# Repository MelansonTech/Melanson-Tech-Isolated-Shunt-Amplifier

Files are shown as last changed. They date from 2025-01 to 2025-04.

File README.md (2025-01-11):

Project Title: Isolated Shunt Amplifier
Overview:
Introducing the Isolated Shunt Amplifier, an open-source electronics project designed to provide precise and isolated measurements in high-voltage applications. This compact amplifier, based on the Si8920, offers flexible gain options, broad bandwidth, and a compact design for accurate and safe signal amplification.
Key Features:
1.	Flexible Gain Options:
•	Times 10 with 500kHz Bandwidth
•	Times 100 with 30kHz Bandwidth
2.	Input Voltage Range:
•	2V to 9V input
3.	Output Voltage Range:
•	+/-6Vout
4.	Input Voltage Common Mode Range:
•	Up to 500Vdc
5.	Compact Design:
•	Space-efficient layout for easy integration into various setups.
6.	Accuracy:
•	Less than 1% error for precise measurements.
Technical Specifications:
•	Amplification Options: Choose between a high gain (times 100) for detailed signal analysis or a moderate gain (times 10) with broader bandwidth for dynamic measurements.
•	Input Voltage Range: Accommodates input voltages ranging from 2V to 9V, providing flexibility for a variety of applications.
•	Common Mode Voltage Handling: Withstands common mode voltages up to 500Vdc, ensuring reliable performance in high-voltage environments.
•	Compact Dimensions: The space-efficient design allows seamless integration into instrumentation setups and constrained spaces.
Intended Use:
The Isolated Shunt Amplifier is tailored for applications where precision, isolation, and flexibility are paramount. It serves as a reliable tool for engineers and researchers working in high-voltage environments, offering accurate signal amplification with customizable gain options.
Application Scenarios:
•	High-Voltage Power Systems Monitoring: Accurately measure and monitor high-voltage power systems with confidence.
•	Electric Vehicle Battery Monitoring: Ensure precise measurements for electric vehicle battery testing and analysis.
•	Industrial Automation: Seamlessly integrate the amplifier into industrial setups requiring isolated and accurate signal amplification.
Open-Source Nature:
This project embraces the open-source philosophy, encouraging collaboration, and customization. The design is open for contributions and modifications, fostering a community-driven approach to electronics development.
Conclusion:
The Isolated Shunt Amplifier stands as a testament to precision and versatility in high-voltage electronics. With customizable gain options, a compact design, and the ability to handle significant common-mode voltages, this open-source project offers a valuable solution for engineers, researchers, and enthusiasts seeking accurate signal amplification in challenging environments.
Explore the Potential of the Isolated Shunt Amplifier in Your High-Voltage Applications. Contribute to the Open-Source Community and Advance Electronics Development Today!

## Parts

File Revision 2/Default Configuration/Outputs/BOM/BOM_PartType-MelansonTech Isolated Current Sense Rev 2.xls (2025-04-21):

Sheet: BOM Report
Bill of Materials |  |  | <Parameter Title not found>
Source Data From: |  | MelansonTech Isolated Current Sense Rev 2.PrjPcb
Project: |  | MelansonTech Isolated Current Sense Rev 2.PrjPcb
Variant: |  | None
Creation Date: | 2025-04-20 | 5:18:39 PM
Print Date: | 2025-04-20 | 17:19:01
Production Quantity: | 100
Currency | CAD
Footprint | Comment | LibRef | Designator | Description | Quantity | Supplier 1 | Supplier Part Number 1 | Supplier Unit Price 1 | Supplier Order Qty 1 | Supplier Subtotal 1 | Manufacturer 1 | Manufacturer Part Number 1
CAP, 0805, HD | CC0805KRX7R9BB104 | Cap,0805,100nf,50V,5%,CC0805KRX7R9BB104 | C1, C2, C4, C5, C6, C19, C21, C24, C25, C26, C27, C31, C32 | CAP CER 0.1UF 50V X7R 0805 | 13 | Digikey | 311-1140-6-ND |  |  |  | Loading... | Loading...
Cap,0805 | CL21A226MAQNNNE | Cap,0805,22uF,25V,X5R,±20%,CL21A226MAQNNNE | C3, C10, C14, C20, C22, C29, C30, C33, C34, C35, C36, C37, C38, C39, C40 | CAP CER 22UF 25V X5R 0805 | 15 | Mouser | 187-CL31B226KPHNNNE |  |  |  | Loading... | Loading...
Cap,5mm Lead Spaceing,14mm HIGH,10MM Dia, Polymer - RA1 | A750MV108M1EAAE014 | Cap,Polar,TH,1000uF,25V,Polymer,±20%,A750MV108M1EAAE014 | C7 | 1000 µF 25 V Aluminum - Polymer Capacitors Radial, Can 14mOhm 2000 Hrs @ 105°C | 1 | Digi-Key | 399-A750MV108M1EAAE014-ND | 0.81871 | 100 | $81.87 | KEMET | A750MV108M1EAAE014
CAP, 0805, HD | CC0805JRNPO9BN561 | Cap,0805,560pF,50V,±5%,C0G,NP0,CC0805JRNPO9BN561 | C8 | CAP CER 560PF 50V C0G/NPO 0805 | 1
CAP, 0805, HD | CL21B473KCFNNNE | Cap,0805,47nF,100V,±10%,CL21B473KCFNNNE | C9 | CAP CER 0.047UF 100V X7R 0805 | 1 | Digikey | 1276-2960-1-ND | 0.03119 | 100 | $3.12 | Samsung | CL21B473KCFNNNE
Cap, 1206 | CL31B475KBHNNNE | Cap,1206,4.7uF,10%,50V,CL31B475KBHNNNE | C11, C12 | Cap,SMD,MLCC,4u7,50V,X7R,10%,1206 | 2 | LCSC | C51205 |  |  |  | Supplier disabled | Supplier disabled
Cap,0805 | CC0805KRX7R9BB104 | Cap,0805,100nf,50V,5%,CC0805KRX7R9BB104 | C13 | CAP CER 0.1UF 50V X7R 0805 | 1 | Digikey | 311-1140-6-ND |  |  |  | Loading... | Loading...
Cap, 5mm Lead Spaceing, 4mm dai | S102K33Y5PP63K5R | Cap,TH,Ceramic,5mm Spacing,1nF,2kV, S102K33Y5PP63K5R | C15 | CAP CER 1000PF 2KV Y5P RADIAL | 1
CAP, 0805, HD | CC0805CRNPO9BN3R0 | CAP,0805,3pF,COG,NPO,CC0805CRNPO9BN3R0 | C16, C17, C28 | CAP CER 3PF 50V C0G/NPO 0805 | 3 | Future Electronics | 9724337 |  |  |  | Loading... | Loading...
CAP, 0805, HD | CC0805KPX7R9BB332 | Cap,0805,3.3nF,50V,±10%,CC0805KPX7R9BB332 | C18 | CAP CER 3300PF 50V X7R 0805 | 1
Cap,0805 | CC0805JRNPO9BN561 | Cap,0805,560pF,50V,±5%,C0G,NP0,CC0805JRNPO9BN561 | C23 | CAP CER 560PF 50V C0G/NPO 0805 | 1
CAP, 0805, HD | C0805X102J1GACAUTO | Cap,0805,1nF,±5%,100Vdc,CL10F104ZB8NNNC | C41 | CAPACITOR, 1NF, 100V, NP0, 0805 | 1 | Digi-Key | 399-19430-1-ND | 0.27568 | 100 | $27.57 | KEMET | C0805X102J1GACAUTO
CM Choke,SMD, DR331 | DR331-105BE | common mode, 1mH@100kHz, 500mA, SMD,2ln, DR331-105BE | CM1 | CMC 1MH 500MA 2LN SMD | 1
SOD123 | MBR0560 | Diode,SOD123,Shottky,60V,0.5A,MBR0560 | D1, D3 | Dio,Sig,Schtky,0.5A,60V,SOD123 | 2 | Digi-Key | MBR0560TPMSCT-ND | 0.11053 | 200 | $22.11 | MCC | MBR0560-TP
LED,TH,T1,3MM-Vert | OVLBB4C7 | LED,TH,T1,3mm,Blue,OVLBB4C7 | D4, D5 | Blue 470nm LED Indication - Discrete 3.2V Radial | 2
SOT23-3 | BAT54SLT1G | Diode,Shottky,Array,Series,30V,200mA,BAT54SLT1G | D6 | Diode Array 1 Pair Series Connection Schottky 30V 200mA (DC) Surface Mount TO-236-3, SC-59, SOT-23-3 | 1 | Digi-Key | BAT54SLT1GOSCT-ND |  |  |  | Loading... | Loading...
CINCH_142-0701-801 | 142-0701-801 | Conn,SMA,Female,End Launch,142-0701-801 | J1 | CONN SMA JACK STR 50OHM EDGE MNT | 1 | Digi-Key | J502-ND | 3.83801 | 100 | $383.80 | Emerson | 142-0701-801
TERM BLOCK 2POS SIDE ENTRY 5MM | TE Connectivity 282836-2 | TERM BLOCK 2POS SIDE ENTRY 5MM, 282836-2 | J2 | Wire to Board 2 Position 5 mm Pitch 30-16 AWG Euro Style Terminal Block | 1 | TME
Connector,Barrel,2.1mm,5.5mm,DC power Jack | PJ-002A | Connector,Barrel,ID 2.1mm,OD 5.5mm,Power Connect, PJ-002A | J4 | Power Barrel Connector Jack 2.10mm ID (0.083"), 5.50mm OD (0.217") Through Hole, Right Angle | 1 | Digi-Key | CP-002A-ND | 0.54016 | 100 | $54.02 | CUI Devices | PJ002A
Ind, 0805 | MLZ2012N6R8LT000 | Ind,0805,6.8uH,550mA,0.25O, MLZ2012N6R8LT000 | L2 | FIXED IND 6.8UH 550MA 250 MOHM | 1 | Digi-Key | 445-6761-1-ND | 0.08667 | 100 | $8.67 | TDK | MLZ2012N6R8LT000
Symbol,Open Source - No Text | Open Source Logo | Symbol,Open Source | Logo1 | Open Source Silk Screen Logo | 1
CONV_PDSE1-S5-S5-S | PDSE1-S5-S5-S | Mod,PSU,4.5-5.5Vin,5Vout,1W, PDSE1-S5-S5-S | Mod1 | DC-DC ISOLATED, 1 W, 4.5-5.5 VDC | 1 | Digi-Key | 102-6291-ND |  |  |  | Loading... | Loading...
SOT23-3 | SSM3K329R,LF | MOSFET.N-Chan, SOT-23-3,3.5A,30V,1W,SSM3K329R,LF | Q1, Q3 | N-Channel 30V 3.5A (Ta) 1W (Ta) Surface Mount SOT-23F | 2 | Digi-Key | SSM3K329RLFDKR-ND | 0.60369 | 200 | $120.74 | Toshiba | SSM3K329R,LF
SOT23-3 | 2N7002ET1G | MOSFET,N-Channel,SOT23,0.25A,60V,2N7002ET1G | Q2, Q4, Q5, Q6 | Small Signal MOSFET, 60 V, 310 mA, Single, N-Channel, 3-Pin SOT-23, Pb-Free, Tape and Reel | 4 | Digi-Key | 2N7002ET1GOSCT-ND | 0.07187 | 400 | $28.75 | ON Semiconductor | 2N7002ET1G
res, 0805, HD | RNCS0805BKE10R0 | Res,0805,10.0O,0.1%,±25ppm/°C,0.1W,RNCS0805BKE10R0 | R1, R12 | RES 10 OHM 0.1% 1/10W 0805 | 2
res, 0805, HD | RR1220P-8251-D-M | Res,0805,8.25KO,0.5%,±25ppm/°C,RR1220P-8251-D-M | R2, R9, R35 | RES SMD 8.25KOHM 0.5% 1/10W 0805 | 3 | Mouser | 754-RR1220P-8251D-M |  |  |  | Loading... | Loading...
res, 0805, HD | RG2012P-103-B-T5 | Res,0805,10.0kO,0.1%,±25ppm/°C,RG2012P-103-B-T5 | R3, R20, R21, R32 | RES SMD 10K OHM 0.1% 1/8W 0805 | 4 | Future Electronics | 4000243 |  |  |  | Loading... | Loading...
res, 0805, HD | CRCW0805100RJNEAC | Res,0805,100O,5%,±200ppm/°C | R4, R8 | RES 100 OHM 5% 1/8W 0805 | 2 | Digi-Key | 541-100ACT-ND | 0.02587 | 200 | $5.17 | Vishay Dale | CRCW0805100RJNEA
Res 2512 | CRA2512-FZ-R010ELF | Res,2512,10mO,3.00W,±1%,CRA2512-FZ-R010ELF | R5 | Resistor; Metal Film; Res 0.01 Ohms; Pwr-Rtg 3 W; Tol 1%; SMT; 2512; Current Sense | 1 | Arrow Electronics | CRA2512-FZ-R010ELF |  | 100 |  | Bourns | CRA2512-FZ-R010ELF
res, 0805, HD | ERA-6AEB9763V | Res,0805,976KO,±0.1%,±25ppm/°C,ERA-6AEB9763V | R6, R24 | RES SMD 976K OHM 0.1% 1/8W 0805 | 2 | Mouser | 667-ERA-6AEB9763V |  |  |  | Loading... | Loading...
res, 0805, HD | ERA-6AEB471V | Res,0805,470O,±0.1%,±25ppm/°C,ERA-6AEB471V | R7, R10, R11, R14, R16, R18 | RES SMD 470 OHM 0.1% 1/8W 0805 | 6
res, 0805, HD | Vishay / Dale CRCW080510K0FKTA | Res,0805,10.0kO,1%,100 ppm,CRCW080510K0FKTA | R13, R15, R19, R23, R27 | RES SMD 10K OHM 1% 1/8W 0805 | 5 | Digi-Key | 541-3016-1-ND |  |  |  | Loading... | Loading...
res, 0805, HD | ERA-6AEB104V | Res,0805,100K,±0.1%,±25ppm/°C,ERA-6AEB104V | R17, R22, R25, R26, R29 | RES SMD 100K OHM 0.1% 1/8W 0805 | 5 | Mouser | 667-ERA-6AEB104V |  |  |  | Loading... | Loading...
Res,SMD,POT,TC33 Series | TC33X-2-101E | Res,POT,SMD,100O,0.1W, TC33X-2-101E | R28 | TRIMMER 100 OHM 0.1W J LEAD TOP | 1 | Digi-Key
res, 0805, HD | RG2012P-824-D-T5 | Res,0805,820KO,±0.1%,±25ppm/°C,RG2012P-824-D-T5 | R30, R31 | RES SMD 820K OHM 0.5% 1/8W 0805 | 2 | Digikey | 408-RG2012P-824-D-T5CT-ND | 0.06382 | 200 | $12.76 | Susumu | RG2012P-824-D-T5
res, 0805, HD | RG2012P-152-B-T5 | Res,0805,1.5KO,0.1%,±25ppm/°C,RG2012P-152-B-T5 | R33 | RES SMD 1.5K OHM 0.1% 1/8W 0805 | 1
Switch,Slide,.SP3T, OS103011 -Side | OS103011MS8QP1 | Switch,TH,Slide,SP3T,100MA,12V,OS103011MS8QP1 | SW1 | SWITCH SLIDE SP3T 100MA 12V | 1 | Digi-Key | CKN9543-ND | 0.87908 | 100 | $87.91 | ITT C&K | OS103011MS8QP1
SOT89-3 | UA78L12ACPKG3 | Reg,Linear,Pos,Fixed,12Vout,27Vin,100mA,UA78L12ACPKG3 | U1 | IC REG LINEAR 12V 100MA SOT89-3 | 1 | Digi-Key | 296-50454-6-ND | 0.22451 | 100 | $22.45 | Texas Instruments | UA78L12ACPKG3
SOIC-8 DWV | SI8921BD-IS4R | IC,CurrentSense,Isolated,8.2 Gain,500Khz,SI8921BD-IS4R | U2 | Isolation IC Inverters, Power Supplies, UPS 8-SOIC | 1 | Digikey | 863-SI8921BD-IS4RCT-ND |  |  |  | Loading... | Loading...
SOT23-5 | OPA197IDBVT | OPAMP, single, General Purpose,Rail-to-Rail,10MHz,SOT-23-5,OPA197IDBVT | U3, U8 | General Purpose Amplifier 1 Circuit Rail-to-Rail SOT-23-5 | 2 | LCSC | C131929 |  |  |  | Supplier disabled | Supplier disabled
SOT23-5 | LM7321MF/NOPB | OPAMP,20Mhz,MOSFET DRIVER,SOT23-5,LM7321MF | U5, U9 | Single Rail-to-Rail Input/Output, ±15V, High Output Current and Unlimited Capacitive Load Operational Amplifier, 5-pin SOT-23, Pb-Free | 2 | Digi-Key | LM7321MF/NOPBCT-ND |  |  |  | Loading... | Loading...
SOT89-3 | HT7550-1 | Reg,Linear,Fixed,SOT-89-3,30Vin,5Vout,150mA,HT7550-1 | U6 | LOW DROPOUT REGULATORS(LDO) POSITIVE FIXED 55MV @ 1MA 30V 5V 150MA SOT-89(SOT-89-3) ROHS | 1
 |  |  |  |  | 101 |  |  |  |  | $858.93
Approved |  | Notes

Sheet: Project Information
Project Full Path | C:\Users\shawn\OneDrive\ProjectGitReleases\Melanson-Tech-Isolated-Shunt-Amplifier\Revision 2\MelansonTech Isolated Current Sense Rev 2.PrjPcb
Project Filename | MelansonTech Isolated Current Sense Rev 2.PrjPcb
Variant Name | None
Data-Source Filename | MelansonTech Isolated Current Sense Rev 2.PrjPcb
Data-Source Full Path | C:\Users\shawn\OneDrive\ProjectGitReleases\Melanson-Tech-Isolated-Shunt-Amplifier\Revision 2\MelansonTech Isolated Current Sense Rev 2.PrjPcb
Title | <Parameter Title not found>
Total Quantity | 101
Report Time | 5:18:39 PM
Report Date | 2025-04-20
Report Date & Tine | 2025-04-20 5:18:39 PM
Output Name | BOM_PartType
Output Type | BOM_PartType
Output Generator Name | BOM
Output Generator Description | Bill of Materials

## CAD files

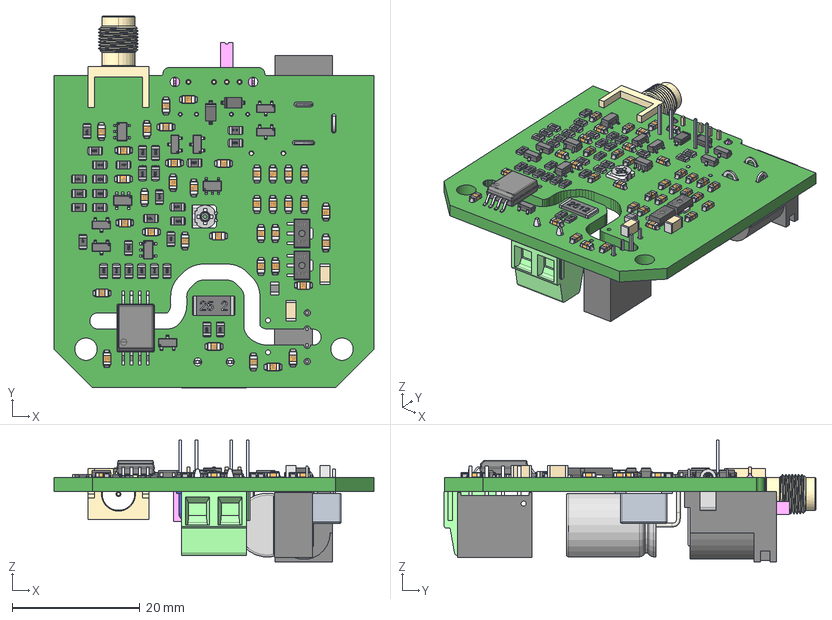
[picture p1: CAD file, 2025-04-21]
Revision 2/Default Configuration/Outputs/ExportSTEP/MelansonTech Isolated Shunt Amplifier Rev 2.step
50.0 x 58.1 x 19.0 mm
Board
User_Library-0805_Cap x 37
0805_Resistor_v11 x 32
SOT23-3 x 7
dr331-105be
pj-002a
TC33_SUBST1
everlight-3MM-LED-BLUE x 2
User_Library-142-0701-801
mkdsn_1.5-2-5.08
SOT23-5_D x 4
BODY-SOIC
LEAD-DWV0008A x 8
User_Library-OS103011MA7QP1
2512_Resistor_v14
CUI_PDSE1-S5-S5-S
Extruded x 9
pin x 2
pin(Mirror) x 2
icbody x 2
Electrolytic_Aluminium_Capacitor-A750MV108M1EAAE014-RA_2_v1

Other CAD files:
Revision 1/Default Configuration/Outputs/ExportSTEP/MelansonTech Isolated Shunt Amplifier.step

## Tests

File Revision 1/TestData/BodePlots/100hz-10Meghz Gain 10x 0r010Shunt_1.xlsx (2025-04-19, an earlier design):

Freq | Gain | Phase | THD
100 | -0.103887 | 0.601408 | 0.460343
125.892541 | -0.116202 | 0.58941 | 0.37386
158.489319 | -0.052079 | 0.019202 | 0.302745
199.526231 | -0.061144 | -0.079171 | 0.392719
251.188643 | -0.139492 | 0.321242 | 0.477265
316.227766 | -0.081056 | -0.273275 | 0.383414
398.107171 | -0.092252 | -0.212315 | 0.416516
501.187234 | -0.101889 | 0.242842 | 0.42893
630.957344 | -0.107038 | -0.276491 | 0.431906
794.328235 | -0.108062 | -0.353769 | 0.43861
1000 | -0.098148 | -0.478633 | 0.48621
1258.925412 | -0.089128 | -0.309933 | 0.462851
1584.893192 | -0.111444 | -0.635607 | 0.433655
1995.262315 | -0.114095 | -0.726018 | 0.45283
2511.886432 | -0.115796 | -0.033487 | 0.532761
3162.27766 | -0.149972 | -1.047474 | 0.485025
3981.071706 | -0.164253 | -1.049516 | 0.541454
5011.872336 | -0.273482 | -1.429288 | 0.51947
6309.573445 | -0.182658 | -1.429573 | 0.544774
7943.282347 | -0.176376 | -1.653607 | 0.567542
10000 | -0.175396 | -2.037027 | 0.624054
12589.25412 | -0.238719 | -1.697526 | 0.694958
15848.93193 | -0.165552 | -2.972292 | 0.575825
19952.62315 | -0.11919 | -3.816541 | 0.683908
25118.86431 | -0.088373 | -4.422099 | 0.85445
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

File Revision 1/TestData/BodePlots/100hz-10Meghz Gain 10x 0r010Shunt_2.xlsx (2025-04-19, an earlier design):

Untitled | Untitled 1 | Untitled 2 | Untitled 3
10000 | 43.174281 | -4.943207 | 0.553689
12589.25412 | 37.710303 | -88.263391 | 0.60362

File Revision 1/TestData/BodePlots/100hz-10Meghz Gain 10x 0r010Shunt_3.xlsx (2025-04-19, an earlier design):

Untitled | Untitled 1 | Untitled 2 | Untitled 3
10000 | -0.217562 | -1.903421 | 0.311509
12589.25412 | -0.223168 | -2.117766 | 0.34443
15848.93193 | -0.180429 | -2.931849 | 0.365195
19952.62315 | -0.149982 | -3.784052 | 0.3532
25118.86431 | -0.150083 | -4.778554 | 0.377886
31622.7766 | -0.050973 | -6.274709 | 0.286165
39810.71706 | 0.030222 | -8.189929 | 0.344575
50118.72336 | 0.160982 | -10.545818 | 0.427985
63095.73445 | 0.214181 | -14.257386 | 0.556753
79432.82347 | 0.313737 | -18.368525 | 0.481052
100000 | 0.434988 | -23.734012 | 0.426826
125892.5412 | 0.541168 | -30.119318 | 0.559736
158489.3192 | 0.735198 | -40.035132 | 0.514767
199526.2315 | 0.901106 | -52.003923 | 0.514315
251188.6432 | 1.069178 | -67.731398 | 0.638013
316227.766 | 1.395142 | -86.361491 | 0.706479
398107.1706 | 1.692426 | -112.784938 | 1.158255
501187.2336 | 2.006206 | -149.080688 | 1.762912
630957.3445 | 1.509511 | 169.248567 | 2.980396
794328.2347 | 0.217531 | 114.234242 | 4.21706
1000000 | -2.307844 | 46.586942 | 4.59348
1200000 | -4.975913 | -80.138786 | 3.761222

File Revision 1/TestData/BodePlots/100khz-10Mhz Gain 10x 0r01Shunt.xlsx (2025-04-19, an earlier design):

Untitled | Untitled 1 | Untitled 2 | Untitled 3
1000 | -0.130753 | -0.36076 | 0.289336
1258.925412 | -0.195913 | -0.367979 | 0.401688
1584.893192 | -0.142182 | -0.619715 | 0.337526
1995.262315 | -0.150131 | -0.698089 | 0.344916
2511.886432 | -0.191351 | -0.716915 | 0.337433
3162.27766 | -0.190165 | -0.935111 | 0.346472
3981.071706 | -0.198442 | -1.082041 | 0.322338
5011.872336 | -0.241096 | -0.840824 | 0.356969
6309.573445 | -0.211067 | -1.344624 | 0.34555
7943.282347 | -0.207584 | -1.624738 | 0.346361
10000 | -0.203895 | -1.897587 | 0.346712
12589.25412 | -0.215949 | -1.929386 | 0.396654
15848.93193 | -0.173807 | -2.947164 | 0.370549
19952.62315 | -0.144607 | -3.798971 | 0.295912
25118.86431 | -0.059679 | -4.612014 | 0.413762
31622.7766 | -0.039152 | -6.164243 | 0.447992
39810.71706 | 0.045976 | -8.162187 | 0.385838
50118.72336 | 0.233227 | -10.508469 | 0.363763
63095.73445 | 0.246157 | -14.083848 | 0.514612
79432.82347 | 0.335988 | -18.492385 | 0.449974
100000 | 0.450799 | -23.912209 | 0.3017
125892.5412 | 0.616913 | -30.012894 | 0.680094
158489.3192 | 0.746656 | -40.091812 | 0.580031
199526.2315 | 0.914746 | -51.642867 | 0.547457
251188.6432 | 1.13561 | -68.272444 | 0.787989
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

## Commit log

2025-04-19 Noise Adjustments and FRA
    Adjusted noise and gain compensation.
    Updated test folder with new fra results
    [100hz-10Meghz Gain 10x 0r010Shunt.xlsx, 100hz-10Meghz Gain 10x 0r010Shunt_1.xlsx, 100hz-10Meghz Gain 10x 0r010Shunt_2.xlsx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]
2025-04-21 Merged Rev 2 and organized
    organized folders and moved Rev 2
    [100hz-10Meghz Gain 10x 0r010Shunt.xlsx, 100hz-10Meghz Gain 10x 0r010Shunt_1.xlsx, 100hz-10Meghz Gain 10x 0r010Shunt_2.xlsx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]
2026-08-21 Add Revision 3 and the project documentation
    Revision 3/ is the current working design from the CircuitStudio folder - the
    alt-shunt amplifier sheet on a newer layout, outputs regenerated March 2026. It
    has NOT been fabricated or tested; Revisions 1 and 2 remain the released
    designs and are untouched by this commit.
    docs/ is new:
    SAFETY.md working voltage, what the isolation does and does not do,
    handling, thermal
    CONNECTORS.md J1/J2/J4 pinouts, SW1 positions, LEDs, output loading
    ASSEMBLY.md fab ordering from the real outputs, assembly, first power-on
    CALIBRATION.md the R28 zero trim (required) and the optional gain correction
    TEST_RECORD.xlsx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
2026-08-21 Input voltage spec is 13-15 V, not 15 V
    Picked up from the README edit made on GitHub. It materially changes finding 2:
    Vin VregIn +12 rail 6 V ref swing above ref 5 A range needs 5 V
    13.0 V 12.63 V 10.93 V 5.47 V 5.32 V OK, 0.32 V margin
    14.0 V 13.63 V 11.93 V 5.97 V 5.82 V OK
    14.9 V 14.53 V 12.00 V 6.00 V 5.85 V regulation starts here
    15.0 V 14.63 V 12.00 V 6.00 V 5.85 V OK
    The board works at 13 V. The rail sags to ~10.9 V and the 6 V reference with
    it, but DiffAmpRef and ISenseRTN come from identical dividers off that same
    rail, so they track and their difference stays nulled; gain is set by resistor
    rati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
2026-08-21 Revision 3.1: rename project documents, regenerate all outputs
    Every document in the Revision 3 project now carries a Rev 3 suffix and lives
    inside Revision 3/, including its own OutJob. The project no longer references
    anything outside its folder, so its outputs can be regenerated from a clean
    checkout. Generated files follow the same convention (...Rev3.GTL, ...Rev3.DRL,
    Pick Place for ...Rev3.csv), so a file's name identifies its board.
    The board is unchanged: 68.25 x 85.00 mm, 4 layers, 95 placements, 163 holes
    across 10 tools, the same four board-scoped design rules. The Gerber set gains
    .GKO, .GM4 and a Dimensions Top layer; the NC drill files drop the -Plated
    suffix.
    The silkscreen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
2026-08-21 Rev 3.1: correct the x50 switch legend to x100, rebuild outputs
    The switch silkscreen now reads Off / x10 / x100, which agrees with the range
    LEDs beside it and with SW1's two active positions in the schematic. There is
    no x50 range and never was one on this board -- the legend was a leftover from
    an earlier design, and it also survives in the Rev 1 Bode sweep filenames.
    Nothing electrical changed. The accuracy tables, the tolerance budget and the
    test record were never affected by the typo.
    Finding 15 in the design review is down to three open items, all silkscreen
    against schematic:
    Supply: 13-16Vdc vs 13-15 V, and Rel1's coil is a 12 V part (15.6 V ceiling)
    Vout +/-6V vs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
2026-08-21 Design review: settle the supply legend at 13-15 V, with the arithmetic
    Finding 15's supply item now carries the reasoning instead of an assertion.
    Rel1's coil is not on a regulated rail -- it sits on HighGain, the range
    switch's own output -- so it follows the input jack, less at most one Schottky
    drop, with nothing between to limit it:
    13 V in -> 12.6-13.0 V coil -> 105-108% of the 12 V rating
    15 V in -> 14.6-15.0 V coil -> 122-125%
    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
2026-09-07 Measure the board, and correct what the measurement contradicts
    A Rev 3.1 board characterised end to end on 2026-09-05/06. Most of the
    repository's daggered "derived, still to be confirmed" figures are now
    measured, and three of them were wrong.
    New: docs/TEST_REPORT.md, the raw readings behind it in docs/test-data/,
    and docs/PRODUCT_BRIEF.md.
    Everything the bench could test, the board passed. DC gain came in at
    -0.05% on the x100 range and -0.24% on the x10 -- inside the accuracy
    grade the datasheet reserves for a user-calibrated system, with nothing
    calibrated -- and held across two independent fixtures and both current
    directions. Forward and reverse agree to ~0.1% on both ranges.
    Corr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
2026-09-10 Document 50×58×24 mm extruded enclosure, panel cutouts and sourcing
    The 3D models were listed and never described. Measured from the meshes
    rather than recalled:
    Enclosure Panel A.stl 58.000 x 24.000 x 1.646 mm, 7 cutouts
    Enclosure Panel B.stl 58.000 x 24.000 x 1.646 mm, 3 cutouts
    Shunt Amp BumperV2.stl 62.000 x 28.000 x 12.000 mm
    Both panels carry Ø2.75 mm fixings on 52.00 mm centres at mid-height, which
    with the 50 mm board length identifies the case as the generic
    50 x 58 x 24 mm split extruded-aluminium type sold under many white-label
    names. Sourcing is therefore given as a dimension string and a list of live
    listings rather than a part number, with Hammond 1455 and Poly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
2026-10-29 Layout and system review of Rev 3.1, 2026-10-29: gates, isolation geometry, rails, thermal, LTspice chain, EMC, DFM, sourcing; findings register; report, PDF and page
2026-10-29 Proposal: single-source reference trim (recommendation 1) - proved schematics, LTspice benches, page
2026-10-30 Proposal: the reference-trim schematics now run in LTspice as they are
    ref_asbuilt.asc and ref_proposed.asc carry the supplies, the trimmer halves as a
    stepped parameter (k = wiper position), an Ios source for the bias-imbalance term
    and the model include. ref_trim_asc.py proves each three ways: LTspice netlist
    against the ref_trim.py bench (0 differences), a batch run against ref_trim.json
    (0.12 / 0.23 uV), and a render. LM7321_12V.lib is copied beside the .asc files
    and ignored (vendor notice). Page and figures regenerated.
2026-10-30 Reference-trim schematics redrawn for LTspice: op-amp triangles, measured text metrics
    The buffers are drawn as op-amp triangles (IN+ top, IN- bottom, V+/V- stubs,
    OUT at the apex) instead of a box with pin names in it. Annotation uses the
    text size measured on LTspice 24 (13 units per character, 30-unit line pitch),
    shunt-part notes start below the line they hang from, net labels sit where
    LTspice draws them. Proved as before: 0 netlist differences, 0.12 / 0.23 uV
    against the bench, 0 overlaps.
2026-10-30 Reference-trim schematics regenerated to Shawn's hand-redraw conventions
    From the hand edit of ref_proposed.asc (netlist unchanged, reading changed):
    parts to a rail rise to a rail label (C29 to Vin), a part between two drawn
    nodes goes between them (C26 is a loop under R21), the trimmer sits beside
    R33 at the left of its row, net names end their lines, a far return is a
    vertical stub with a rotated name. The symbol carries Value only, which
    removes LTspice's "Sub-circuit name listed twice" warning; text sits on the
    8 grid LTspice snaps to. Proved as before: 0 netlist differences,
    0.12 / 0.23 uV against the bench, 0 overlaps, no log warnings.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
